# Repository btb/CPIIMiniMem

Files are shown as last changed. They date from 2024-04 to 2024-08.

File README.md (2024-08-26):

# Compaq Portable II Mini Memory Expansion

## TODO

More investigation of the possibility of using higher-density SIMMs.

SIMM socket just a smidge too close to the ICs. They'll hit if the ICs use sockets.

Placement of Bank3-4 expanson connector probably renders the nearby mounting hole useless.

Overlap of Bank3-4 expansion connector with SIMM socket not ideal.

SIMM could be turned around and hang over battery.

Can probably make a few mm bigger.

Would be nice if main connector was easier to align.

Find correct size standoffs.

## About

This is a 512K expansion board which connects directly to the motherboard of the Compaq Portable II.

Based on the reverse-engineered [System Memory Board](https://github.com/btb/PortableIIMemBoard).

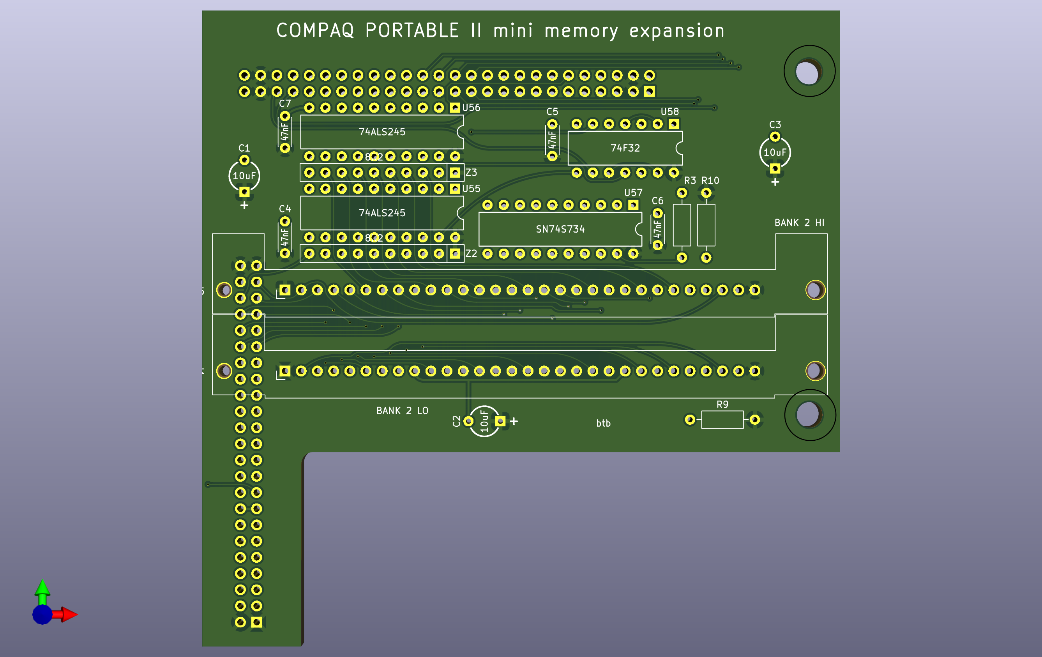
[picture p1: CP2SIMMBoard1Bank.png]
render


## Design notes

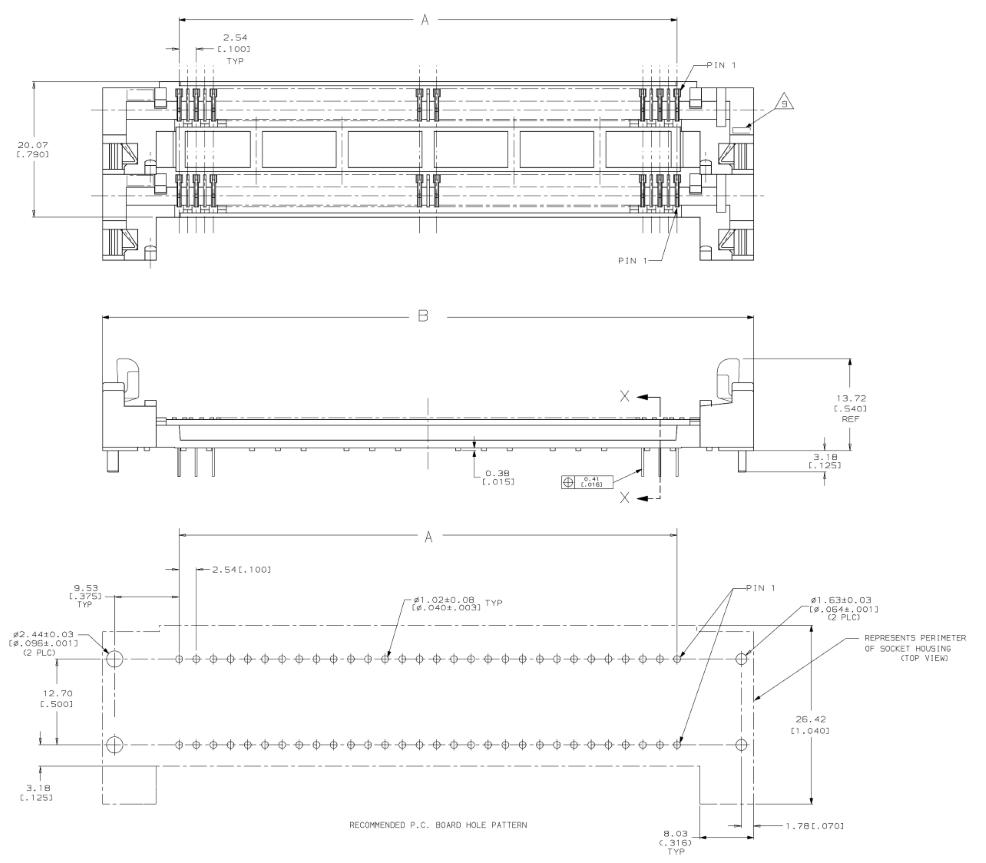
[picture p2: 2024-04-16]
datasheets/hws9229-1.jpg

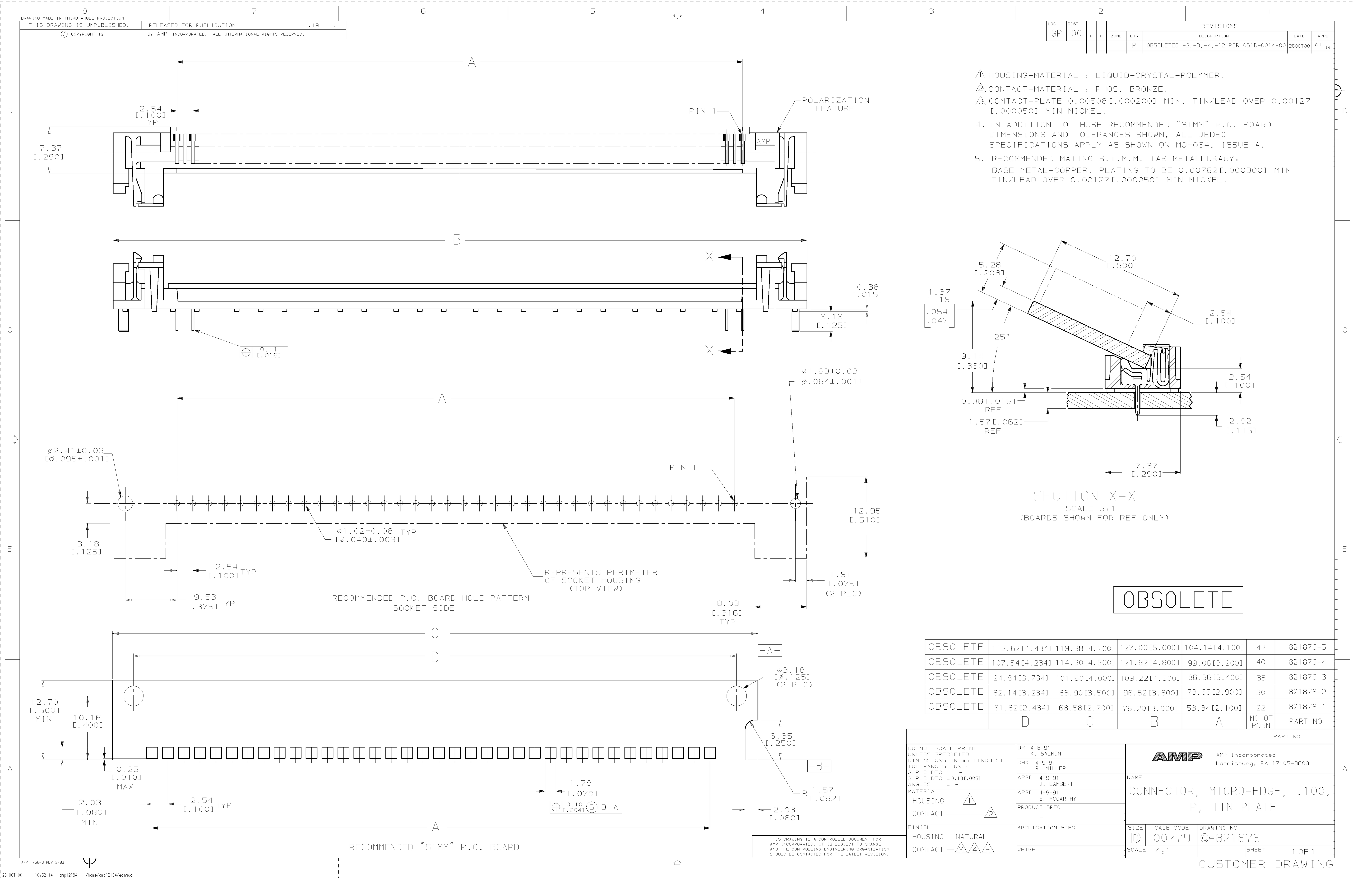
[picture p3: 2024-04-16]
datasheets/ENG_CD_821876_P copy.png

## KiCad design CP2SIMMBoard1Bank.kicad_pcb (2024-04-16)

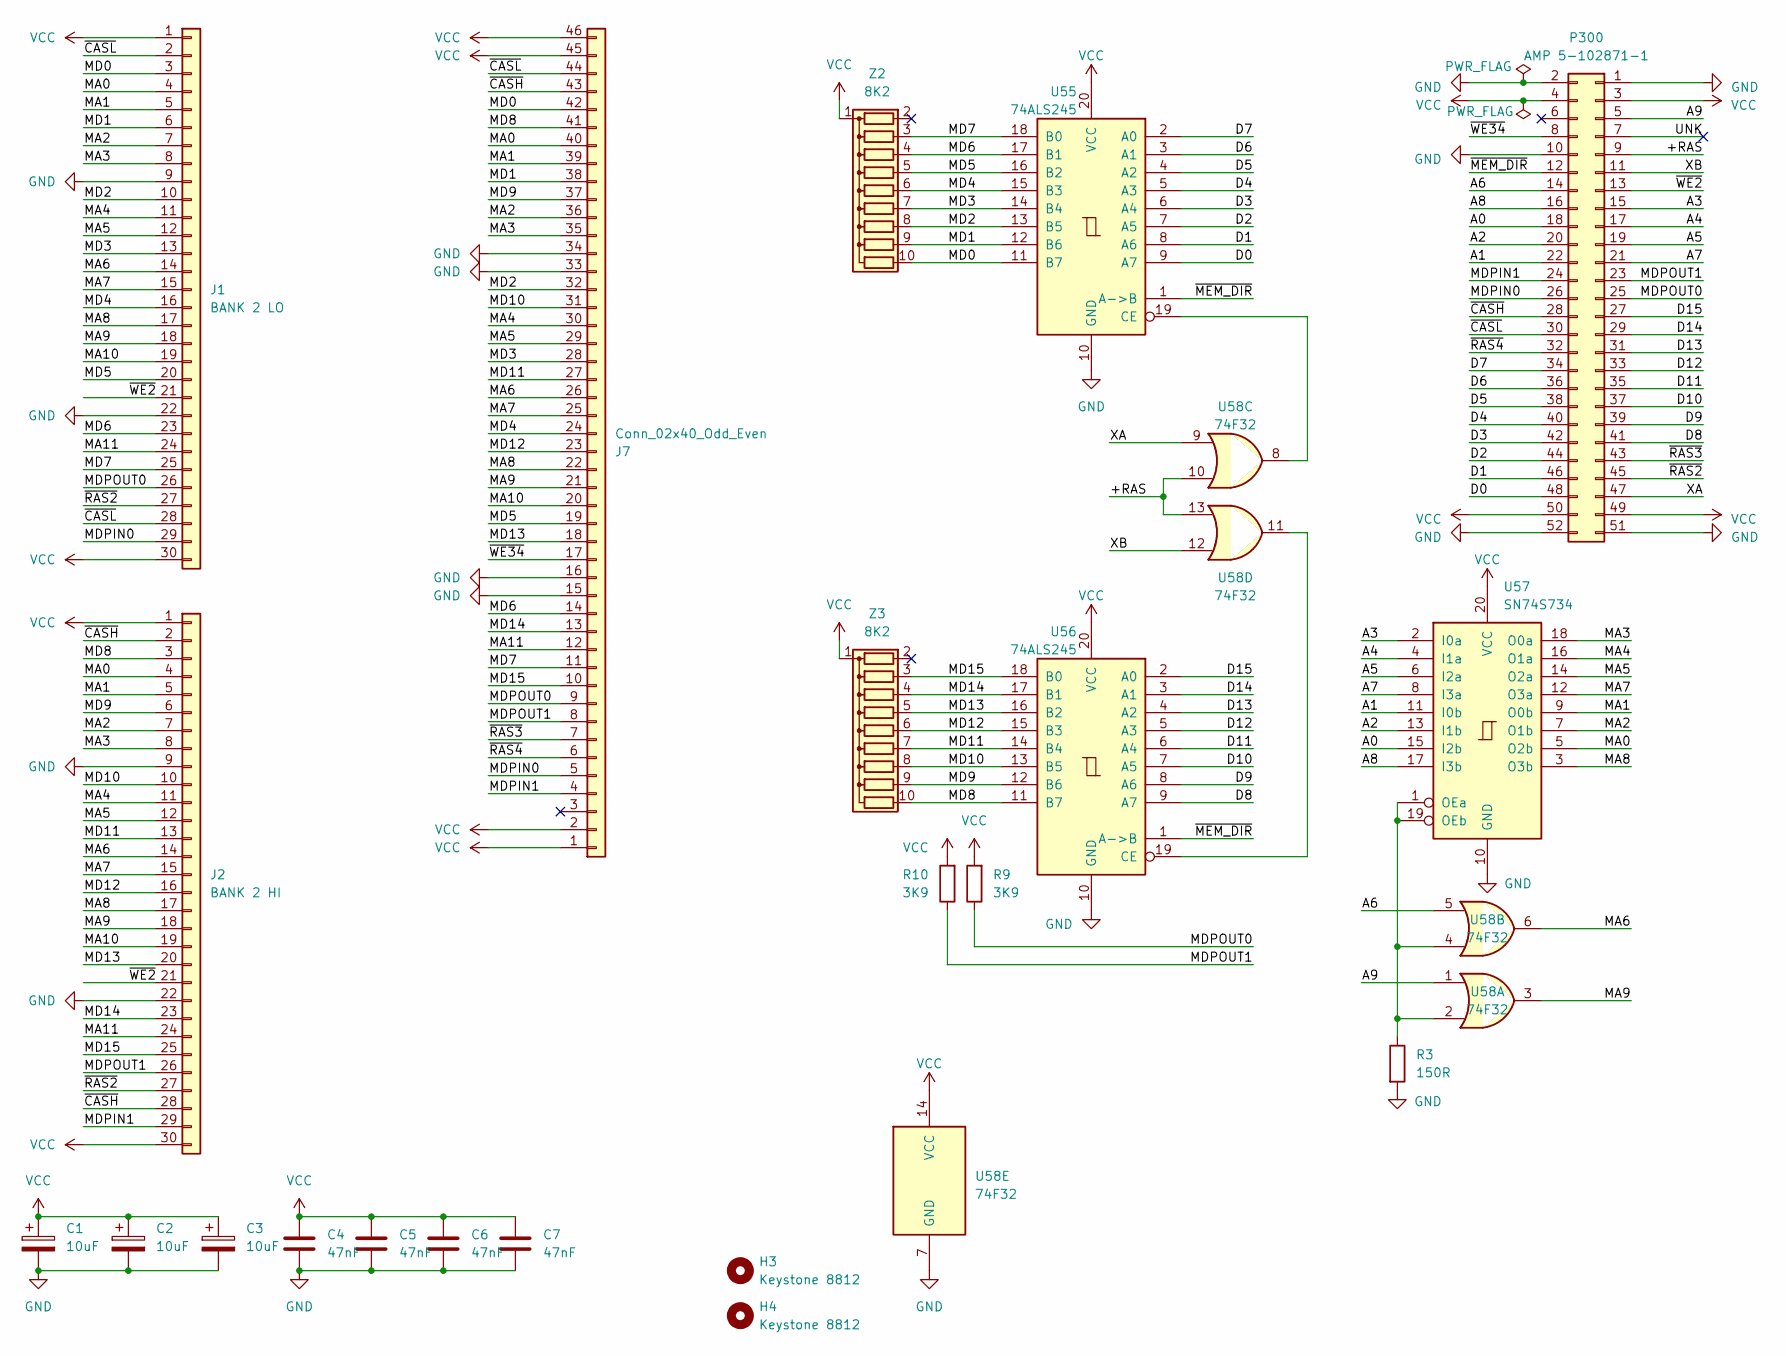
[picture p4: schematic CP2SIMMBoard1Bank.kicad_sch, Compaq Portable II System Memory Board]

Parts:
C1, C2, C3: 10uF; CP_Radial_Tantal_D4.5mm_P5.00mm
C4, C5, C6, C7: 47nF; C_Disc_D4.3mm_W1.9mm_P5.00mm
H3, H4: Keystone 8812; MountingHole_4mm
J1: BANK 2 LO; SIMMSocket30Pin
J2: BANK 2 HI; SIMMSocket30Pin
J7: Conn_02x40_Odd_Even; PinSocket_2x23_P2.54mm_Horizontal
P300: AMP 5-102871-1; PinHeader_2x26_P2.54mm_Vertical
R3: 150R; R_Axial_DIN0207_L6.3mm_D2.5mm_P10.16mm_Horizontal
R9, R10: 3K9; R_Axial_DIN0207_L6.3mm_D2.5mm_P10.16mm_Horizontal
U55, U56: 74ALS245; DIP-20_W7.62mm
U57: SN74S734; DIP-20_W7.62mm
U58: 74F32; DIP-14_W7.62mm
Z2, Z3: 8K2; R_Array_SIP10

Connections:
/+RAS: P300.9, U58.10, U58.13
/A0: P300.18, U57.15 (I2b)
/A1: P300.22, U57.11 (I0b)
/A2: P300.20, U57.13 (I1b)
/A3: P300.15, U57.2 (I0a)
/A4: P300.17, U57.4 (I1a)
/A5: P300.19, U57.6 (I2a)
/A6: P300.14, U58.5
/A7: P300.21, U57.8 (I3a)
/A8: P300.16, U57.17 (I3b)
/A9: P300.5, U58.1
/D0: P300.48, U55.9 (A7)
/D1: P300.46, U55.8 (A6)
/D2: P300.44, U55.7 (A5)
/D3: P300.42, U55.6 (A4)
/D4: P300.40, U55.5 (A3)
/D5: P300.38, U55.4 (A2)
/D6: P300.36, U55.3 (A1)
/D7: P300.34, U55.2 (A0)
/D8: P300.41, U56.9 (A7)
/D9: P300.39, U56.8 (A6)
/D10: P300.37, U56.7 (A5)
/D11: P300.35, U56.6 (A4)
/D12: P300.33, U56.5 (A3)
/D13: P300.31, U56.4 (A2)
/D14: P300.29, U56.3 (A1)
/D15: P300.27, U56.2 (A0)
/MA0: J1.4, J2.4, J7.40, U57.5 (O2b)
/MA1: J1.5, J2.5, J7.39, U57.9 (O0b)
/MA2: J1.7, J2.7, J7.36, U57.7 (O1b)
/MA3: J1.8, J2.8, J7.35, U57.18 (O0a)
/MA4: J1.11, J2.11, J7.30, U57.16 (O1a)
/MA5: J1.12, J2.12, J7.29, U57.14 (O2a)
/MA6: J1.14, J2.14, J7.26, U58.6
/MA7: J1.15, J2.15, J7.25, U57.12 (O3a)
/MA8: J1.17, J2.17, J7.22, U57.3 (O3b)
/MA9: J1.18, J2.18, J7.21, U58.3
/MA10: J1.19, J2.19, J7.20
/MA11: J1.24, J2.24, J7.12
/MD0: J1.3, J7.42, U55.11 (B7), Z2.10 (R9)
/MD1: J1.6, J7.38, U55.12 (B6), Z2.9 (R8)
/MD2: J1.10, J7.32, U55.13 (B5), Z2.8 (R7)
/MD3: J1.13, J7.28, U55.14 (B4), Z2.7 (R6)
/MD4: J1.16, J7.24, U55.15 (B3), Z2.6 (R5)
/MD5: J1.20, J7.19, U55.16 (B2), Z2.5 (R4)
/MD6: J1.23, J7.14, U55.17 (B1), Z2.4 (R3)
/MD7: J1.25, J7.11, U55.18 (B0), Z2.3 (R2)
/MD8: J2.3, J7.41, U56.11 (B7), Z3.10 (R9)
/MD9: J2.6, J7.37, U56.12 (B6), Z3.9 (R8)
/MD10: J2.10, J7.31, U56.13 (B5), Z3.8 (R7)
/MD11: J2.13, J7.27, U56.14 (B4), Z3.7 (R6)
/MD12: J2.16, J7.23, U56.15 (B3), Z3.6 (R5)
/MD13: J2.20, J7.18, U56.16 (B2), Z3.5 (R4)
/MD14: J2.23, J7.13, U56.17 (B1), Z3.4 (R3)
/MD15: J2.25, J7.10, U56.18 (B0), Z3.3 (R2)
/MDPIN0: J1.29, J7.5, P300.26
/MDPIN1: J2.29, J7.4, P300.24
/MDPOUT0: J1.26, J7.9, P300.25, R9.1
/MDPOUT1: J2.26, J7.8, P300.23, R10.1
/UNK: P300.7
/XA: P300.47, U58.9
/XB: P300.11, U58.12
/~CASH: J2.2, J2.28, J7.43, P300.28
/~CASL: J1.2, J1.28, J7.44, P300.30
/~MEM_DIR: P300.12, U55.1 (A->B), U56.1 (A->B)
/~RAS2: J1.27, J2.27, P300.45
/~RAS3: J7.7, P300.43
/~RAS4: J7.6, P300.32
/~WE2: J1.21, J2.21, P300.13
/~WE34: J7.17, P300.8
GND: C1.2, C2.2, C3.2, C4.2, C5.2, C6.2, C7.2, J1.9, J1.22, J2.9, J2.22, J7.15, J7.16, J7.33, J7.34, P300.1, P300.2, P300.10, P300.51, P300.52, R3.2, U55.10 (GND), U56.10 (GND), U57.10 (GND), U58.7 (GND)
unnamed: U55.19 (CE), U58.8
unnamed: U56.19 (CE), U58.11
unnamed: R3.1, U57.1 (OEa), U57.19 (OEb), U58.2, U58.4
VCC: C1.1, C2.1, C3.1, C4.1, C5.1, C6.1, C7.1, J1.1, J1.30, J2.1, J2.30, J7.1, J7.2, J7.45, J7.46, P300.3, P300.4, P300.49, P300.50, R9.2, R10.2, U55.20 (VCC), U56.20 (VCC), U57.20 (VCC), U58.14 (VCC), Z2.1 (common), Z3.1 (common)

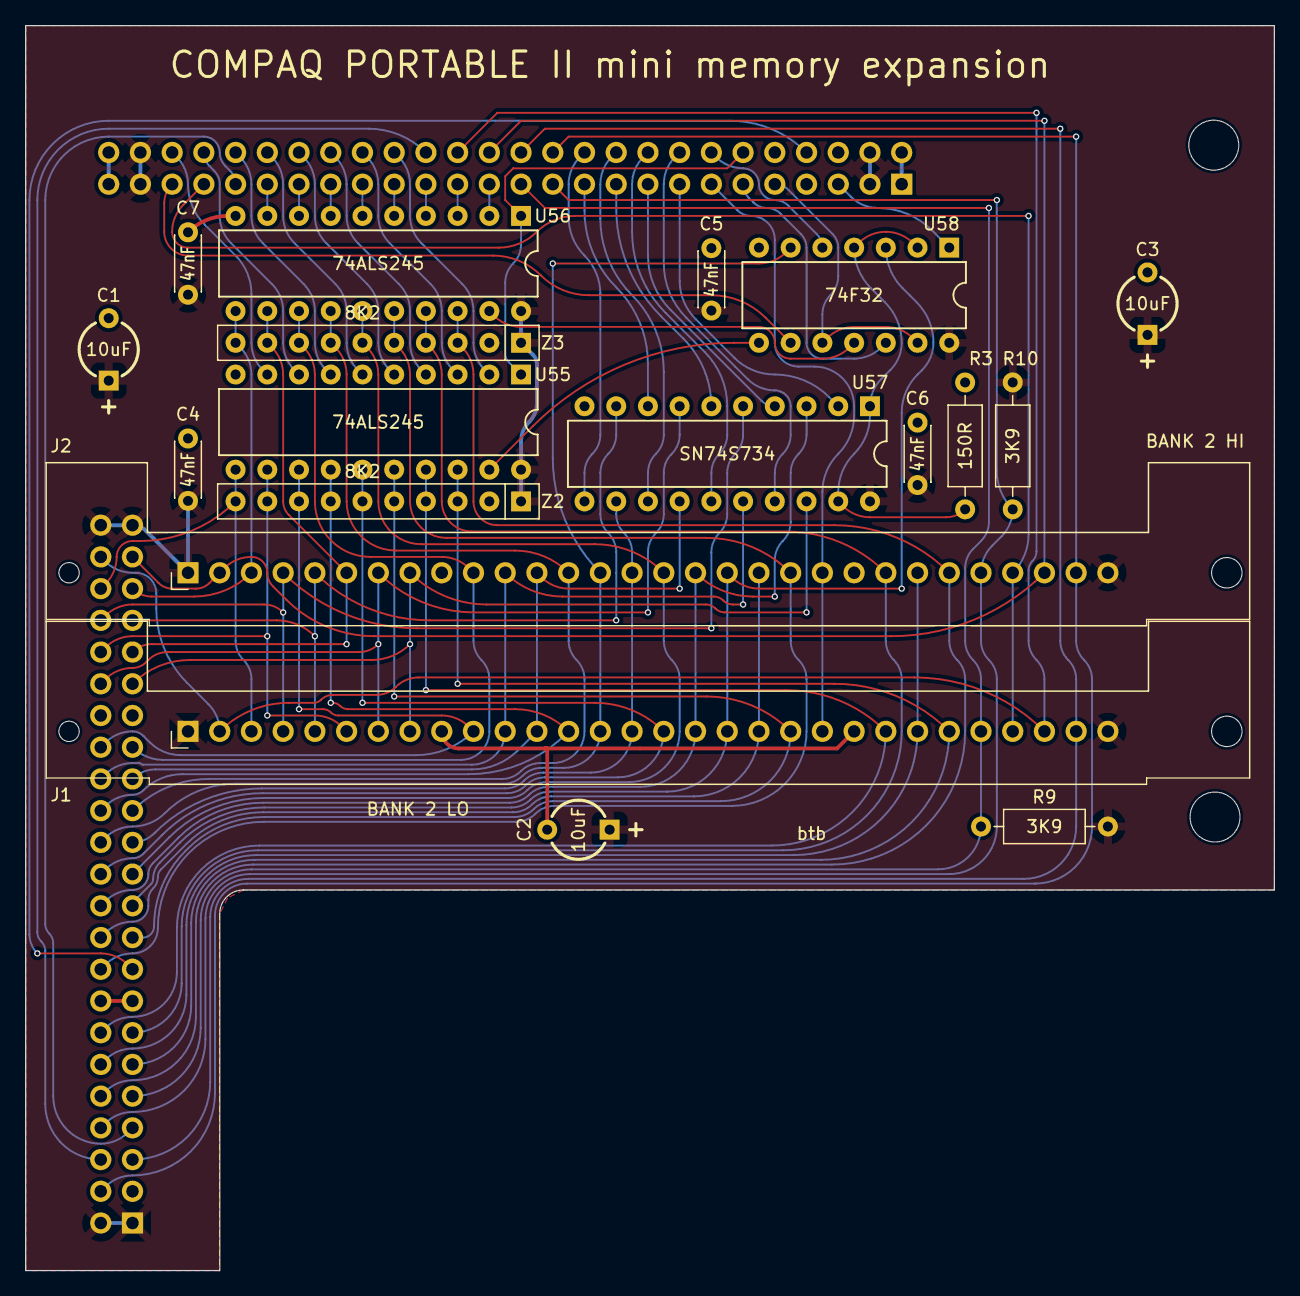
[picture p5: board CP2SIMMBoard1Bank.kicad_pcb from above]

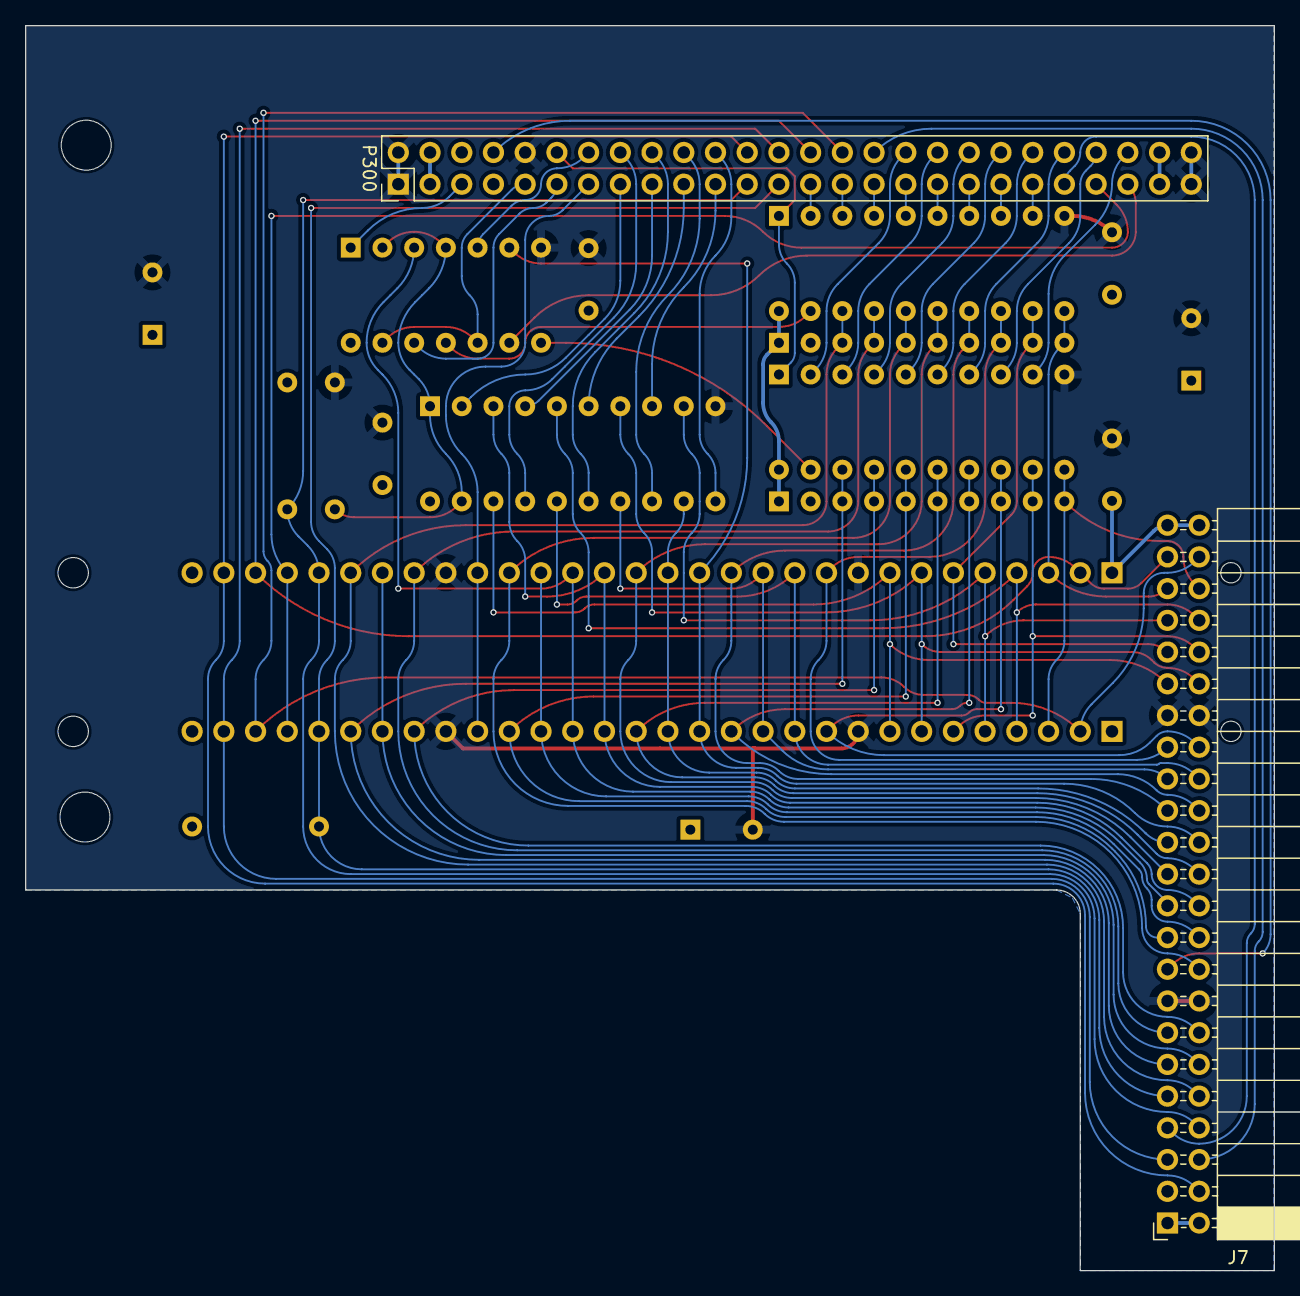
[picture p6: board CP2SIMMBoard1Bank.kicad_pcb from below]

Board: 2 copper layers, 100.0 x 99.7 mm, 22 parts (2 on the bottom side), 74 nets.

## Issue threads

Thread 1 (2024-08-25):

Would it be okay to download your project, convert it to Gerber files, and then manufacture the PCB?

drawingangnam, 2024-08-25:
Hello. I pay my respects to your wonderful project.
It's a grateful gift for someone like me who loves retro devices.
I think my CP2 will become even more amazing.
Would it be okay if I download this project and manufacture the PCB?

btb, 2024-08-25:
You certainly may do that, yes. This is still just a first revision, though it does work. Note that since it only has one bank of simms, it currently only supports adding 512K of RAM.

Closed 2024-08-26.
